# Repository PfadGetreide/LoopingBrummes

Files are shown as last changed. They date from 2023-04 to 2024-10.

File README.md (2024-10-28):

# Looping Brummes
Looping Louie is a game of skill for children produced by Milton Bradley since 
1994 (<a href="https://en.wikipedia.org/wiki/Loopin'_Louie">Wikipedia</a>).
Abused and very popular among alcoholics at parties, was it my intention to 
modify and personalize this game.The outcome is called "Looping Brummes". 
The main function of this mod is to control the speed of the little guy flying 
in circles. In addition there is the possibility to randomize the speed and even
the direction.



This repository mod consist of the following:
<ul>
  <li>KiCAD files for the PCB</li>
  <li>source code for the controls</li>
  <li>3D-models for the case and the lighting mod</li>
</ul> 

# KiCAD
One part of the project is a custom PCB containing a DC-motor controller, a 
step-up converter needed for more speed, a SSD1306 display, a rotary encoder for
menu navigation and a place to solder down a RaspberryPi Pico.



# Source Code
The code is still under construction.But it works :)
Any tips are welcome.

# 3D-models
The models are the case with a top and bottom piece and a mod to hide a LED strip
on the base of the Looping Louie.
For the case, you will need 4 M4 heat inserts and 4 M4x10 screws.





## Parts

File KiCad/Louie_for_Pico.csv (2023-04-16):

Source: | C:\Users\mazze\Documents\KiCad\Projekte\Looping Louie\Louie_for_Pico\Louie_for_Pico\Louie_for_Pico.kicad_sch
Date: | 13.10.2022 09:55:17
Tool: | Eeschema (6.0.4)
Generator: | C:\Program Files\KiCad\6.0\bin\scripting\plugins/bom_csv_grouped_by_value_with_fp.py
Component Count: | 20
Ref | Qnty | Value | Cmp name | Footprint | Description | Vendor
Brd1, | 1 | SSD1306 | SSD1306 | SSD1306:SSD1306-0.91-OLED-4pin-128x32 | SSD1306 OLED
C1, C2, | 2 | 1u | C | Capacitor_SMD:C_1206_3216Metric_Pad1.33x1.80mm_HandSolder | Unpolarized capacitor
D1, | 1 | 1N5819 | 1N5819 | Diode_SMD:D_SOD-123F | 40V 1A Schottky Barrier Rectifier Diode, DO-41
IC1, | 1 | TB67H451AFNG,EL | TB67H451AFNG,EL | Samacsys:SOIC127P600X170-9N | Motor/Motion/Ignition Controllers & Drivers 50V/3A BRUSHED MOTOR DRIVER
J1, | 1 | Conn_01x03 | Conn_01x03 | Connector_Molex:Molex_KK-254_AE-6410-03A_1x03_P2.54mm_Vertical | Generic connector, single row, 01x03, script generated (kicad-library-utils/schlib/autogen/connector/)
L1, | 1 | 10u | L | Inductor_SMD:L_Taiyo-Yuden_NR-40xx_HandSoldering | Inductor
M1, | 1 | ~ | Motor_DC | Connector_Molex:Molex_KK-254_AE-6410-02A_1x02_P2.54mm_Vertical | DC Motor
R1, | 1 | 31600 | R | Resistor_SMD:R_1206_3216Metric_Pad1.30x1.75mm_HandSolder | Resistor
R2, | 1 | 5100 | R | Resistor_SMD:R_1206_3216Metric_Pad1.30x1.75mm_HandSolder | Resistor
R3, | 1 | 10k | R | Resistor_SMD:R_1206_3216Metric_Pad1.30x1.75mm_HandSolder | Resistor
R13, R14, | 2 | 5k | R | Resistor_SMD:R_1206_3216Metric_Pad1.30x1.75mm_HandSolder | Resistor
SW2, SW3, SW4, SW5, | 4 | SW_Push | SW_Push | Button_Switch_THT:SW_TH_Tactile_Omron_B3F-10xx | Push button switch, generic, two pins
U1, | 1 | AP3012 | AP3012 | Package_TO_SOT_SMD:SOT-23-5 | 500mA, Adjustable Step-Up Voltage Regulator, 1.5MHz Frequency, SOT-23-5
U2, | 1 | Pico | Pico | Pi Pico:RPi_Pico_SMD_TH
U3, | 1 | EC12D1564402 | EC12D1564402 | Samacsys:EC12D1564402 | ALPS - EC12D1564402 - ENCODER, VERTICAL, 12MM, 30DET,15PPR

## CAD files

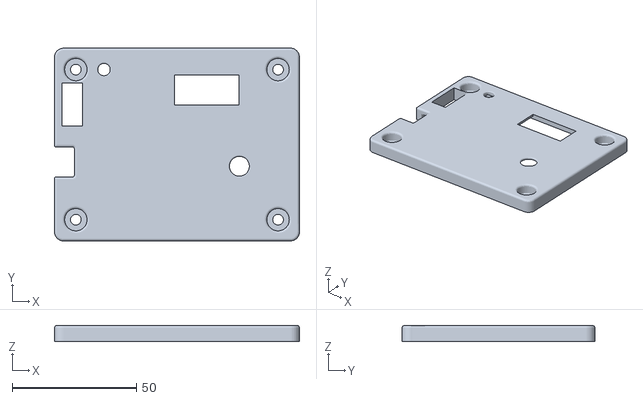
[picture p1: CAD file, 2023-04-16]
3D/Top.stl
98.5 x 77.5 x 6.50

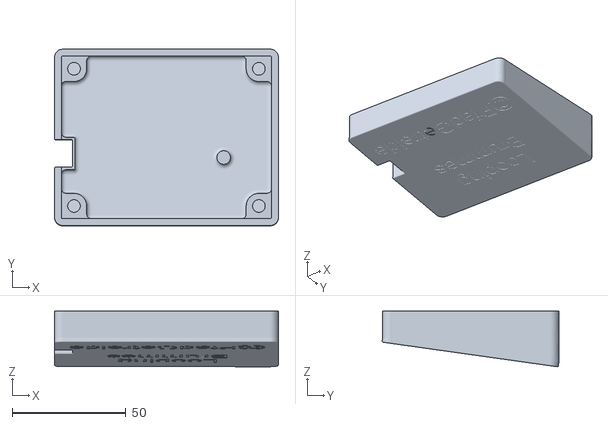
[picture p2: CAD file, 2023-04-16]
3D/Bottom.stl
98.5 x 77.7 x 24.4

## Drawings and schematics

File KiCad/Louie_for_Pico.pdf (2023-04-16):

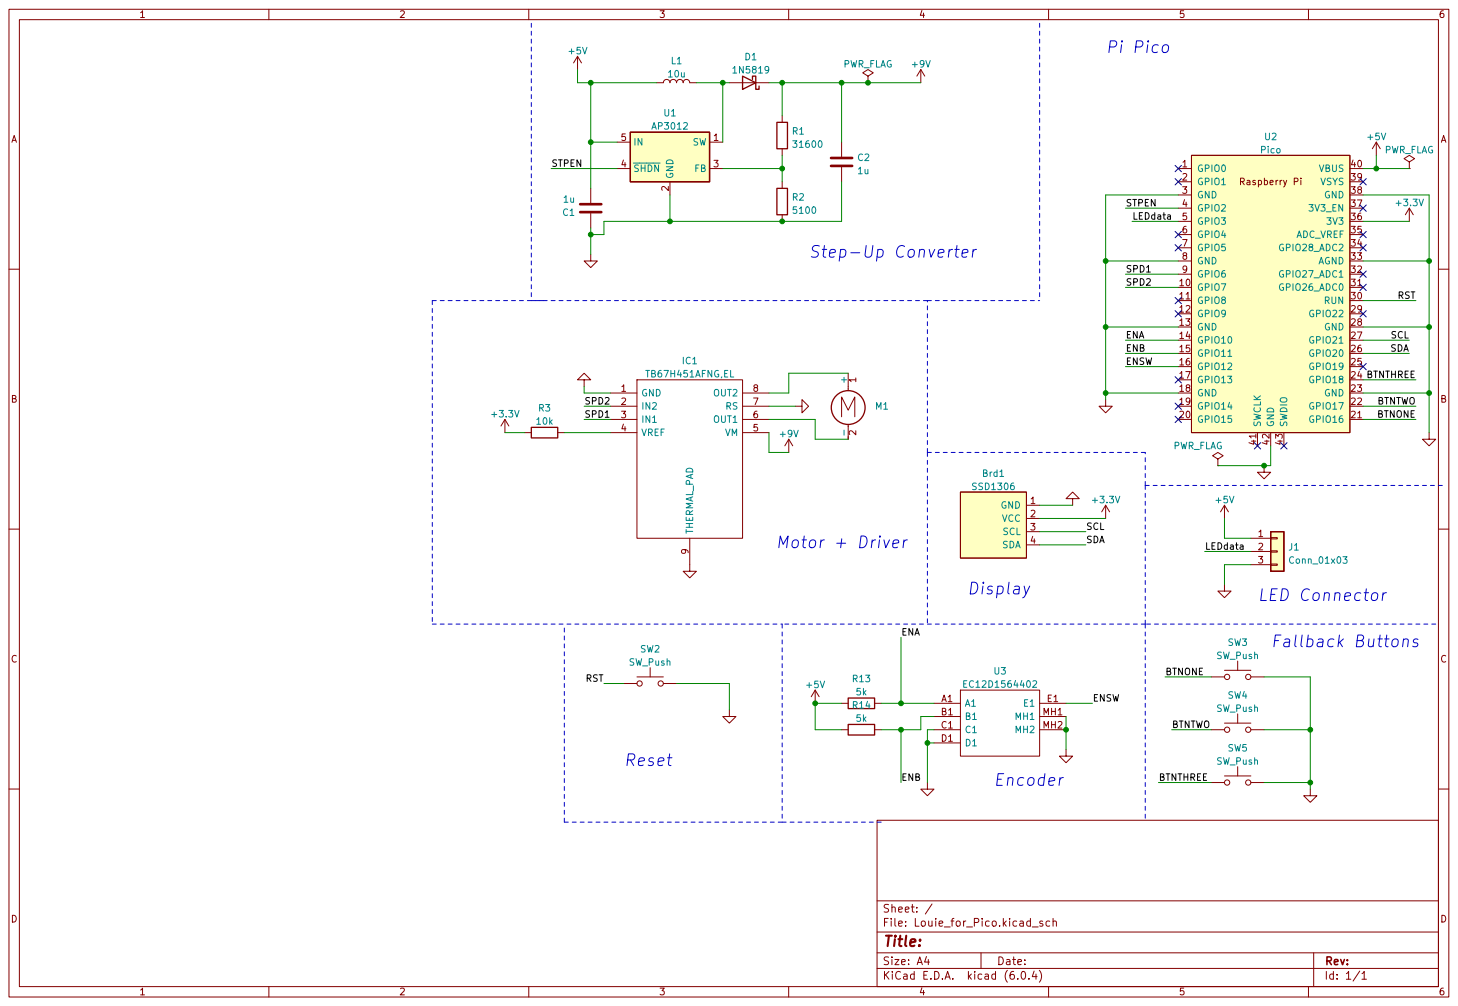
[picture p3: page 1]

LEDdata BTNONE Step-Up Converter

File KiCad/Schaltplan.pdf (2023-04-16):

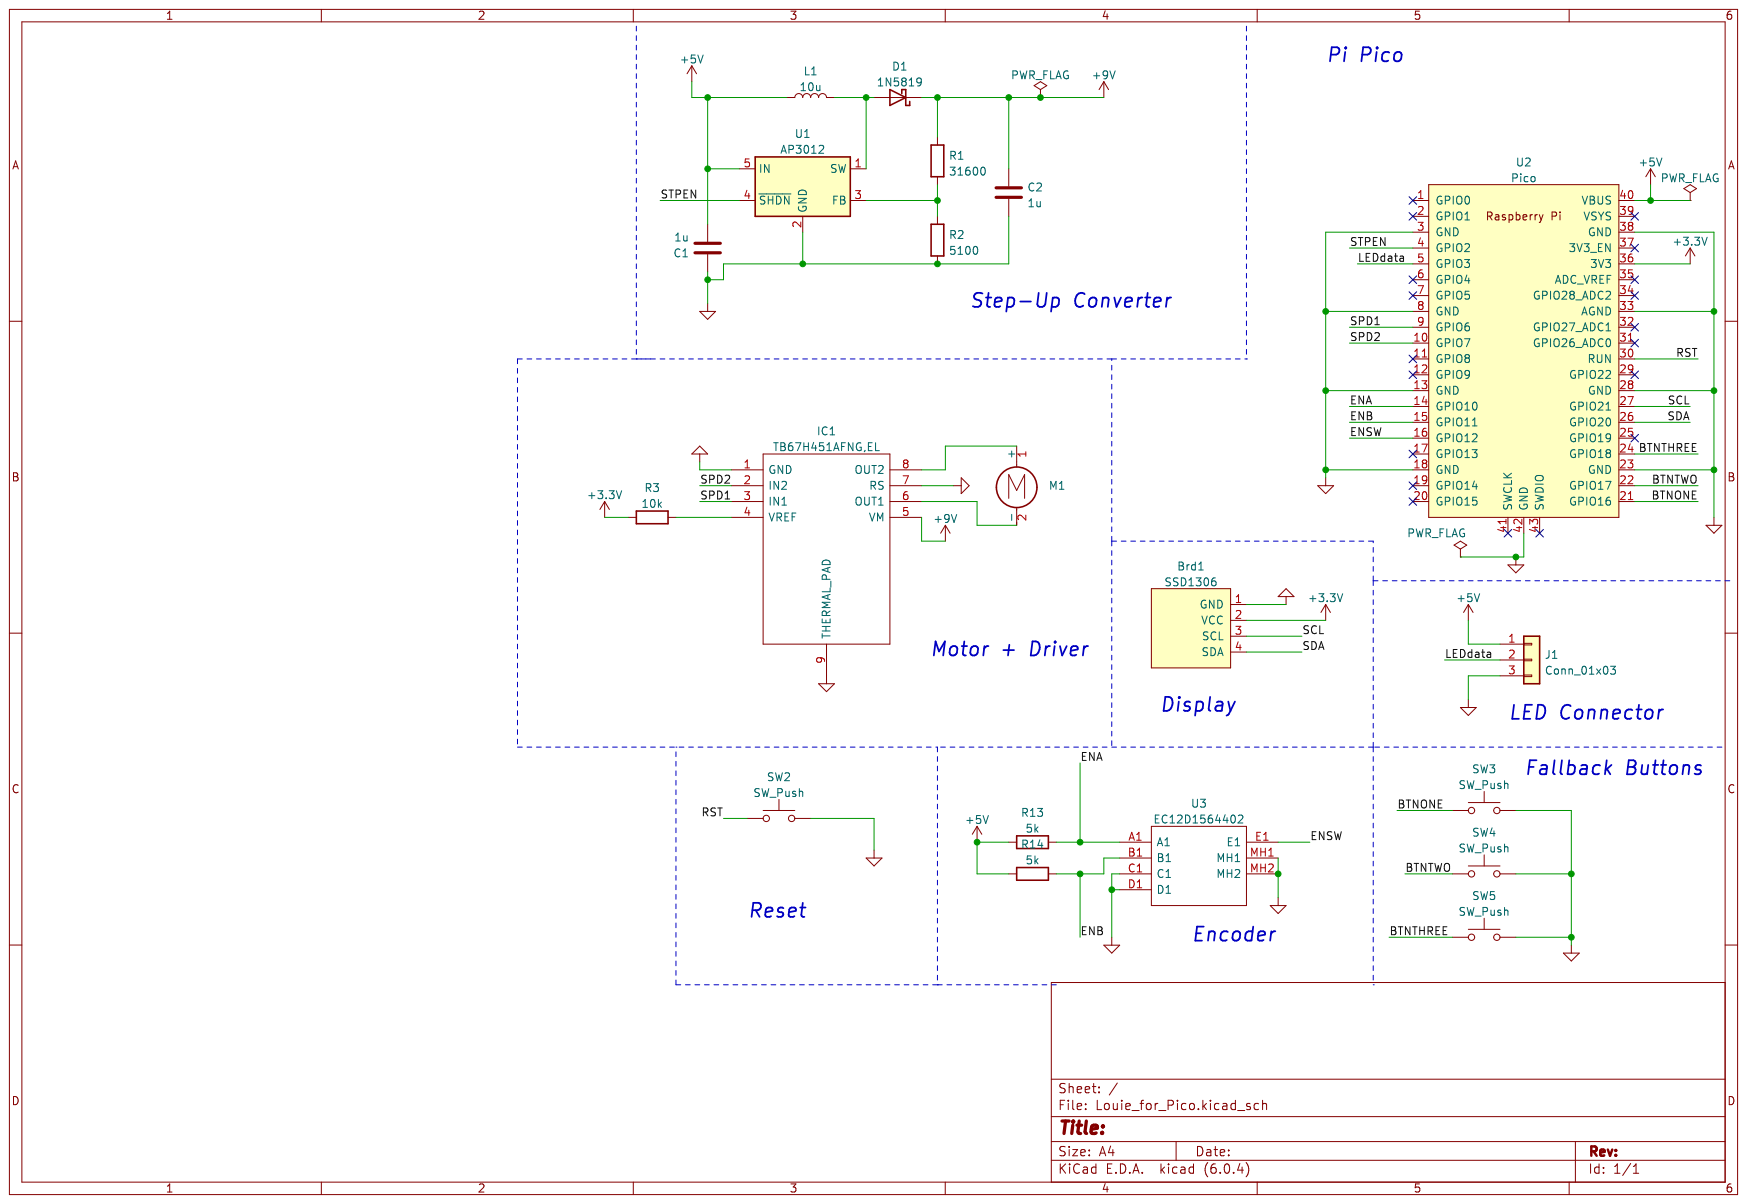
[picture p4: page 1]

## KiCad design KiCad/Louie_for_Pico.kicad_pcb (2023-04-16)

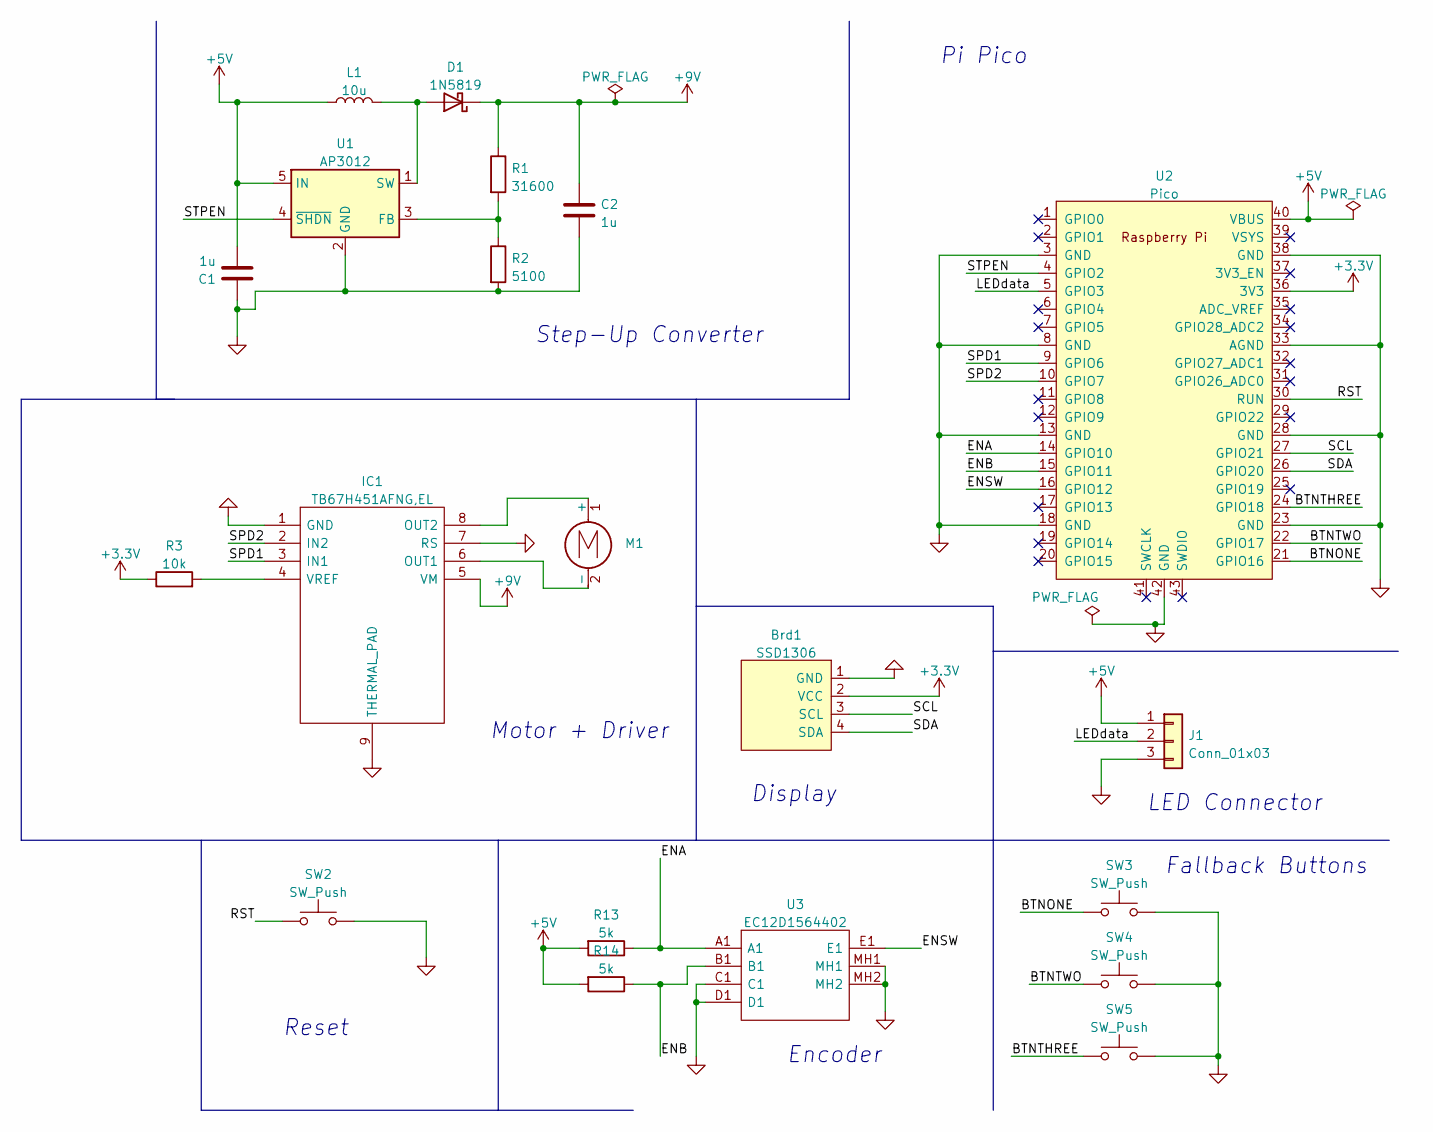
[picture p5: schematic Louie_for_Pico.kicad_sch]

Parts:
Brd1: SSD1306; SSD1306-0.91-OLED-4pin-128x32
C1, C2: 1u; C_1206_3216Metric_Pad1.33x1.80mm_HandSolder
D1: 1N5819; D_SOD-123F
IC1: TB67H451AFNG,EL; SOIC127P600X170-9N; Mouser Part Number 757-TB67H451AFNGEL
J1: Conn_01x03; Molex_KK-254_AE-6410-03A_1x03_P2.54mm_Vertical
L1: 10u; L_Taiyo-Yuden_NR-40xx_HandSoldering
M1: Molex_KK-254_AE-6410-02A_1x02_P2.54mm_Vertical
R1: 31600; R_1206_3216Metric_Pad1.30x1.75mm_HandSolder
R2: 5100; R_1206_3216Metric_Pad1.30x1.75mm_HandSolder
R3: 10k; R_1206_3216Metric_Pad1.30x1.75mm_HandSolder
R13, R14: 5k; R_1206_3216Metric_Pad1.30x1.75mm_HandSolder
SW2, SW3, SW4, SW5: SW_Push; SW_TH_Tactile_Omron_B3F-10xx
U1: AP3012; SOT-23-5
U2: Pico; RPi_Pico_SMD_TH
U3: EC12D1564402; Mouser Part Number 688-EC12D1564402

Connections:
+3V3: Brd1.2 (VCC), R3.1, U2.36 (3V3)
+5V: C1.2, J1.1, L1.1, R13.2, R14.2, U1.5 (IN), U2.40 (VBUS)
+9V: C2.1, D1.1 (K), IC1.5 (VM), R1.1
/BTNONE: SW3.1, U2.21 (GPIO16)
/BTNTHREE: SW5.1, U2.24 (GPIO18)
/BTNTWO: SW4.1, U2.22 (GPIO17)
/ENA: R13.1, U2.14 (GPIO10), U3.A1
/ENB: R14.1, U2.15 (GPIO11), U3.B1
/ENSW: U2.16 (GPIO12), U3.E1
/LEDdata: J1.2, U2.5 (GPIO3)
/RST: SW2.1, U2.30 (RUN)
/SCL: Brd1.3 (SCL), U2.27 (GPIO21)
/SDA: Brd1.4 (SDA), U2.26 (GPIO20)
/SPD1: IC1.3 (IN1), U2.9 (GPIO6)
/SPD2: IC1.2 (IN2), U2.10 (GPIO7)
/STPEN: U1.4 (~SHDN), U2.4 (GPIO2)
GND: Brd1.1 (GND), C1.1, C2.2, IC1.1 (GND), IC1.7 (RS), IC1.9 (THERMAL_PAD), J1.3, R2.2, SW2.2, SW3.2, SW4.2, SW5.2, U1.2 (GND), U2.3 (GND), U2.8 (GND), U2.13 (GND), U2.18 (GND), U2.23 (GND), U2.28 (GND), U2.33 (AGND), U2.38 (GND), U2.42 (GND), U3.C1, U3.D1, U3.MH1, U3.MH2
unnamed: D1.2 (A), L1.2, U1.1 (SW)
unnamed: IC1.4 (VREF), R3.2
unnamed: IC1.6 (OUT1), M1.2 (-)
unnamed: IC1.8 (OUT2), M1.1 (+)
unnamed: R1.2, R2.1, U1.3 (FB)

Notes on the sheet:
Pi Pico
Display
LED Connector
Encoder
Motor + Driver
Fallback Buttons
Step-Up Converter
Reset

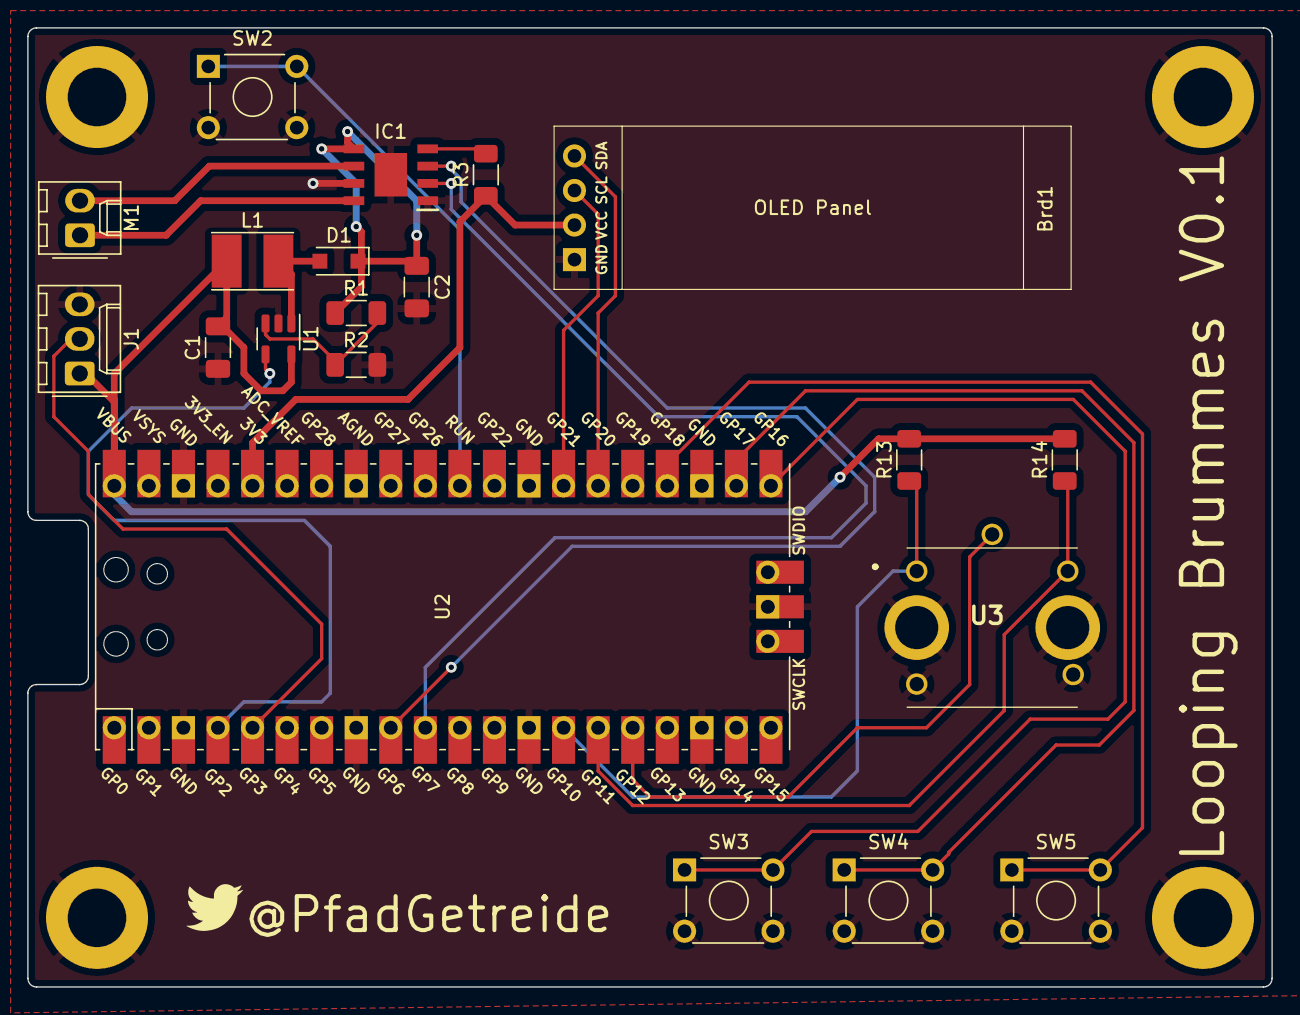
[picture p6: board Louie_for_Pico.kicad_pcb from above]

Board: 2 copper layers, 91.4 x 70.5 mm, 20 parts (0 on the bottom side), 22 nets.

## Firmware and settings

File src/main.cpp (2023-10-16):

// *********************************************************************
// Includes
// *********************************************************************
#include "Control.h"
#include "Encoder.h"
#include "Menu.h"
#include <Adafruit_GFX.h>
#include <Adafruit_NeoPixel.h>
#include <Adafruit_SSD1306.h>
#include <Arduino.h>
#include <SPI.h>
#include <Wire.h>

// *********************************************************************
// Defines
// *********************************************************************

// Pins for TB67H451AFNG,EL DC motor driver.
#define CNRTL_PIN_ONE 6 // forward
#define CNRTL_PIN_TWO 7 // backwards

// Pins for addressable rgb data and number of leds
#define LED_PIN 3
#define NUMBER_OF_LEDS 44
#define BRIGHTNESS 10

// Rotary Encoder pins
#define ENCODER_A 10
#define ENCODER_B 11
#define ENCODER_BTN 12

// Display pins
#define WIDTH 128 // OLED display width, in pixels
#define HEIGHT 32 // OLED display height, in pixels

#define OLED_RESET -1

#define ADDRESS 0x3C

// I2C pins for the SSD1306
// changed pins in path below below
// C:\Users\user\.platformio\packages\framework-arduinopico\variants\rpipico
// #define PIN_WIRE0_SDA  20
// #define PIN_WIRE0_SCL  21

// delay pin for step-up converter. Otherwise the pico crashes
#define DELAY_PIN 2

// *********************************************************************
// Global Variables
// *********************************************************************

// change variable if the encoder has moved to change the menu
bool encoderMoved_ = false;

// *********************************************************************
// Objects
// *********************************************************************

Control CNTRL(CNRTL_PIN_ONE, CNRTL_PIN_TWO);
Encoder ENCD(ENCODER_A, ENCODER_B, ENCODER_BTN);
Adafruit_SSD1306 display(WIDTH, HEIGHT, &Wire, OLED_RESET);
Menu MENU(&ENCD, &display);
Adafruit_NeoPixel pixels =
    Adafruit_NeoPixel(NUMBER_OF_LEDS, LED_PIN, NEO_GRB + NEO_KHZ800);

// *********************************************************************
// Functions
// *********************************************************************

void interruptA();
void interruptB();
void interruptBTN();

void setup()
{
    // set delay pin to output
    pinMode(DELAY_PIN, OUTPUT);

    // serial init, only needed for testing purposses
    Serial.begin(9600);
    Serial.print("Morsche");

    // start display
    display.begin(SSD1306_SWITCHCAPVCC, ADDRESS);
    display.setTextColor(SSD1306_WHITE);

    // Menu Begin
    MENU.displayMenu();

    // set Interrupts
    pinMode(ENCODER_A, INPUT_PULLUP);
    pinMode(ENCODER_B, INPUT_PULLUP);
    pinMode(ENCODER_BTN, INPUT_PULLUP);
    attachInterrupt(digitalPinToInterrupt(ENCODER_A), interruptA, CHANGE);
    attachInterrupt(digitalPinToInterrupt(ENCODER_B), interruptB, CHANGE);
    attachInterrupt(digitalPinToInterrupt(ENCODER_BTN), interruptBTN, RISING);

    // start leds
    pixels.begin();
    pixels.setBrightness(BRIGHTNESS);

    // give every led a start colour
    for (int i = 0; i < NUMBER_OF_LEDS; i++)
    {
        pixels.setPixelColor(i, pixels.Color(0, 255, 255));
        pixels.show();
    }

    // wait for everything to stablilize, then start the step-up converter
    delay(1000);
    digitalWrite(DELAY_PIN, HIGH);
}

void loop()
{
    // Check if the encoder was moved
    if (encoderMoved_)
    {
        // Display the menu
        MENU.displayMenu();

        // Reset the encoder moved flag
        encoderMoved_ = false;
    }

    // Set the speed and direction of the LEDs based on the encoder state
    CNTRL.setSpeed(ENCD.getSpeed(), ENCD.getRandomState(), ENCD.getReverseState());

    // Wait for 100ms
    delay(100);

    // If the direction is forward
    if (CNTRL.getDirection())
    {
        // For each LED
        for (int i = 0; i < NUMBER_OF_LEDS; i++)
        {
            // Set the color based on the speed
            pixels.setPixelColor(i, pixels.Color(CNTRL.getSpeed(), (255 - CNTRL.getSpeed()), (255 - CNTRL.getSpeed())));

            // Update the LED
            pixels.show();
        }
    }
    else // If the direction is backward
    {
        // For each LED
        for (int i = 0; i < NUMBER_OF_LEDS; i++)
        {
            // Set the color based on the speed
            pixels.setPixelColor(i, pixels.Color((255 - CNTRL.getSpeed()), CNTRL.getSpeed(), (255 - CNTRL.getSpeed())));

            // Update the LED
            pixels.show();
        }
    }
}

// Interrupt function for encoder pin A
void interruptA()
{
    // Set the encoder moved flag
    encoderMoved_ = true;

    // Call the encoder interrupt function for pin A
    ENCD.interruptA();
}

// Interrupt function for encoder pin B
void interruptB()
{
    // Set the encoder moved flag
    encoderMoved_ = true;

    // Call the encoder interrupt function for pin B
    ENCD.interruptB();
}

// Interrupt function for encoder button
void interruptBTN()
{
    // Set the encoder moved flag
    encoderMoved_ = true;

    // Call the encoder interrupt function for the button
    ENCD.interruptBTN();
}

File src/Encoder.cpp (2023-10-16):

#include "Encoder.h"

Encoder::Encoder(uint8_t a_inputPinA, uint8_t a_inputPinB, uint8_t a_buttonPin)
{
    // Assigning the pin numbers
    inputPinA_ = a_inputPinA;
    inputPinB_ = a_inputPinB;
    buttonPin_ = a_buttonPin;

    // Reading the initial states of the input pins
    pinAState_ = digitalRead(inputPinA_);
    pinBState_ = digitalRead(inputPinB_);

    // Initializing the menu position, encoder speed and speed percentage
    // variables
    menuPos_ = 0;
    encoderSpeed_ = 0;
    speedPercentage_ = 0;

    // Initializing the debounce time and last interrupt time
    lastInterruptTime_ = 0;
    interruptTime_ = 0;
    debounceTime_ = 20;

    // Setting the maximum number of menu items
    maxMenuItems_ = 3;

    // Initializing the random, reverse and speed select states
    randomONencoder_ = false;
    reverseONencoder_ = false;
    speedSelectState_ = false;
}

void Encoder::interruptA()
{
    interruptTime_ = millis();
    // debounce
    if (interruptTime_ - lastInterruptTime_ > debounceTime_)
    {

        // Debounce again (maybe unnecessary)
        if (digitalRead(inputPinA_) != pinAState_)
        {
            // Update the pin A state
            pinAState_ = !pinAState_;
            if (pinAState_ && !pinBState_)
            {
                if (speedSelectState_)
                {
                    speedPercentage_ += 5;
                    if (speedPercentage_ > 100)
                    {
                        speedPercentage_ = 0;
                    }
                    encoderSpeed_ = static_cast<uint8_t>(
                        (static_cast<float>(speedPercentage_) / 100) * 255);
                    // Serial.println(encoderSpeed_);
                }
                else
                {
                    menuPos_ += 1;
                    if (menuPos_ >= maxMenuItems_)
                    {
                        menuPos_ = 0;
                    }
                }
                // Serial.println(menuPos_);
            }
            lastInterruptTime_ = interruptTime_;
        }
    }
    Serial.println("A ");
    Serial.print("A State: ");
    Serial.println(pinAState_);
    Serial.print("B State: ");
    Serial.println(pinBState_);
    Serial.print("Menu Position: ");
    Serial.println(menuPos_);
    interruptTime_ = millis();
}

void Encoder::interruptB()
{
    interruptTime_ = millis();
    // debounce
    if (interruptTime_ - lastInterruptTime_ >
        debounceTime_) // Check if enough time has passed since the last
                       // interrupt
    {

        // Debounce again maybe unnecessary
        if (digitalRead(inputPinB_) !=
            pinBState_) // Check if the input pin B has changed since the last
                        // interrupt
        {
            pinBState_ = !pinBState_;
            if (pinBState_ && !pinAState_)
            {
                if (speedSelectState_)
                {
                    speedPercentage_ -= 5;
                    if (speedPercentage_ > 100)
                    {
                        speedPercentage_ = 100;
                    }
                    encoderSpeed_ = static_cast<uint8_t>(
                        (static_cast<float>(speedPercentage_) / 100) * 255);
                    // Serial.println(encoderSpeed_);
                }
                else
                {
                    // cycle to the first menu item
                    menuPos_ -= 1;
                    if (menuPos_ >= maxMenuItems_)
                    {
                        menuPos_ = maxMenuItems_ - 1;
                    }
                }
            }
            lastInterruptTime_ = interruptTime_;
        }
    }
    Serial.println("b ");
    Serial.print("A State: ");
    Serial.println(pinAState_);
    Serial.print("B State: ");
    Serial.println(pinBState_);
    Serial.print("Menu Position: ");
    Serial.println(menuPos_);
}

void Encoder::interruptBTN()
{
    interruptTime_ = millis(); // Get current time in milliseconds
    // debounce
    if (interruptTime_ - lastInterruptTime_ >
        debounceTime_) // Check if enough time has passed since the last
                       // interrupt
    {

        // state change for if the button was pressed when in menu state
        if (menuPos_ ==
            0) // Check if we are currently in the "speed select" menu
        {
            // Serial.println("speedselect");
            speedSelectState_ =
                !speedSelectState_; // Toggle the speed select state
        }
        if (menuPos_ ==
            1) // Check if we are currently in the "random select" menu
        {
            // Serial.println("randomselect");
            randomONencoder_ =
                !randomONencoder_; // Toggle the random select state
        }
        if (menuPos_ ==
            2) // Check if we are currently in the "reverse select" menu
        {
            // Serial.println("reverseselect");
            reverseONencoder_ =
                !reverseONencoder_; // Toggle the reverse select state
        }
    }
    // Debugging-Ausgabe
    Serial.print("Menu Position: ");
    Serial.println(menuPos_);
}

uint8_t Encoder::getMenuPosition()
{
    return menuPos_;
} // Return the current menu position

bool Encoder::getRandomState()
{
    return randomONencoder_;
} // Return the current random select state

bool Encoder::getReverseState()
{
    return reverseONencoder_;
} // Return the current reverse select state

uint8_t Encoder::getSpeedPercentage()
{
    return speedPercentage_;
} // Return the current speed percentage

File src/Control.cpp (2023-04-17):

#include "Control.h"

// Constructor, sets the output pins for the motor control and initializes
// variables
Control::Control(uint8_t a_outputPinOne, uint8_t a_outputTwo)
{
    outputPinOne_ = a_outputPinOne;
    outputPinTwo_ = a_outputTwo;
    pinMode(outputPinOne_, OUTPUT);
    pinMode(outputPinTwo_, OUTPUT);
    oldTime_ = 0;
    newTime_ = 0;
    randomTime_ = random(500, 5000);
    actualSpeed = 0;
}

// Sets the speed and direction of the motor
// maxSpeed: the maximum speed of the motor
// rndParam: if true, randomly changes speed and direction of the motor at
// random intervals rvrsParam: if true, sets the motor direction to reverse
void Control::setSpeed(uint8_t maxSpeed, bool rndParam, bool rvrsParam)
{

    newTime_ = millis();

    // Random mode
    if (rndParam)
    {

        // Check if it's time to change speed and direction
        if ((newTime_ - oldTime_) >= randomTime_)
        {

            // Random mode with reverse
            if (rvrsParam)
            {

                // Randomly drive forward or backward at a random speed
                long rndRnd = (random(0, 9));
                if (rndRnd > 4)
                {
                    driveBackwards = true;
                }
                else
                {
                    driveBackwards = false;
                }

                // Drive backwards
                if (driveBackwards)
                {
                    actualSpeed = random(SLOW_SPEED, maxSpeed);
                    analogWrite(outputPinOne_, OFF_SPEED);
                    analogWrite(outputPinTwo_, actualSpeed);
                }
                else
                {
                    // Drive forwards
                    actualSpeed = random(SLOW_SPEED, maxSpeed);
                    analogWrite(outputPinOne_, actualSpeed);
                    analogWrite(outputPinTwo_, OFF_SPEED);
                }
            }
            else
            {
                driveBackwards = false;
                actualSpeed = random(SLOW_SPEED, maxSpeed);
                analogWrite(outputPinOne_, actualSpeed);
                analogWrite(outputPinTwo_, OFF_SPEED);
            }
            randomTime_ = random(500, 5000);
            oldTime_ = newTime_;
        }
    }
    else
    // Random mode without reverse
    {
        // Non-random mode with reverse
        if (rvrsParam)
        {
            // Drive backward at the maximum speed
            driveBackwards = true;
            actualSpeed = maxSpeed;
            analogWrite(outputPinOne_, OFF_SPEED);
            analogWrite(outputPinTwo_, maxSpeed);
        }
        else // Non-random mode without reverse
        {
            // Drive forward at the maximum speed
            driveBackwards = false;
            actualSpeed = maxSpeed;
            analogWrite(outputPinOne_, maxSpeed);
            analogWrite(outputPinTwo_, OFF_SPEED);
        }
    }
}

// Returns the current speed of the motor

uint8_t Control::getSpeed() { return actualSpeed; }

// Returns the current direction of the motor (true for forward, false for
// backward)
bool Control::getDirection() { return !driveBackwards; }

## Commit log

2023-04-13 wire edit
2023-04-16 3d models, kicad, geting code running w platformio
    [Bottom.stl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]
